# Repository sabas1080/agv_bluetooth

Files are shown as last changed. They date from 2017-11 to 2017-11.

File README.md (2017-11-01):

## AGV Bluetooth

AGV

Proyecto de AGV con Bluetooth y AppInventor

Proyecto publicado originalmente en mi antiguo blog [TecnologicoBJ12](http://tecnologicobj12.blogspot.mx/2011/12/control-de-un-carro-por-bluetooth.html)

Andrés Sabas @ 2011

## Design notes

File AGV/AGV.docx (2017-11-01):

INSTITUTO TECNOLOGICO DE AGUASCALIENTES

# PROYECTO AGV

INGENIERIA MECANICA

JOSUE ISAI LUEVANO MASIAS

GUSTAVO MUÑOZ LOPEZ

IVAN ALEJANDRO ORTEGA MONTAÑEZ

COLABORACION ESPECIAL:

ANDRES EDUARDO SABAS JIMENEZ

12/12/2011

AGUASCALIENTES, AGS

# Introducción

Los AGV son vehículos equipados con sistemas de guiado automática, ópticos o electromagnéticos. Pueden seguir rutas predeterminadas y tener capacidad de programación, selección de paradas, bloqueos, y otras características que requiere el control del sistema. Son vehículos equipados con sistemas de guiado automático, ópticos o electromagnéticos. Pueden seguir rutas predeterminadas y tener capacidad de programación, selección de paradas, bloqueos y otras características que requiere el control del sistema.

- Tipos:
  - Vehículos de remolque.
  - Unidades de carga.
  - Remolque de palets.
  - Tipo carretilla elevadora.
  - Vehículos de baja capacidad de carga.
- Funciones:
  - Guiado.
  - Elección de ruta.
  - Control de tráfico:
    - Control por zonas.
    - Detección de otros AG.
    - Control combinado.
  - Transferencia de la carga:
    - Manual.
    - Carga y descarga automática.
    - Rodillos y cadenas.
    - Elevadores.
    - Empujadores.
  - Gestión del sistema:
    - Técnicas de asignación de vehículos:
      - A bordo. Fuera del AGV.
      - Terminal remoto.
      - Computador central.
      - Combinación de las anteriores.
    - Monitorización.
- Aplicaciones:
  - Cuando los materiales llegan tarde a los centros de trabajo más del 5% del tiempo con un sistema manual.
  - Cuando hay más de carga y descarga en el sistema.
  - Cuando los movimientos de materiales están entre 35 y 200 cargas por hora.
  - Cuando se necesitan tres o cuatro carretillas en mínimo de dos turnos.
  - Cuando se están usando pies de rodillos o cintas transportadoras.
  - Cuando el software de control de la producción requiere conocer en tiempo real la situación de los materiales.
  - Cuando el nivel de inventario debido a piezas en proceso hace difícil subir la productividad.
  - Cuando la automatización de los centros de trabajo requiere una mayor automatización de los sistemas de transporte.
  - Cuando existe gran cantidad de productos dañados con los sistemas de transporte convencional.

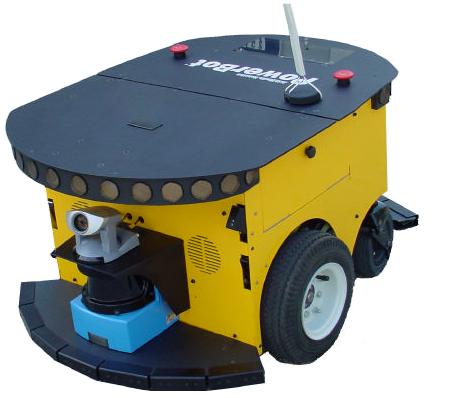
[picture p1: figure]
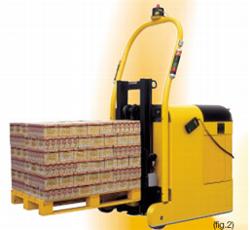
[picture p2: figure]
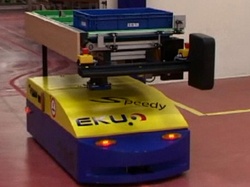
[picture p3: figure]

## Justificación.

Este proyecto estudiará algunas formas de manufactura y analizará cual es mejor en cada ocasión.

Se diseño desde cero el proyecto del AGV para que pueda realizar los parámetros dichos en el curso los cuales eran de una carga de 250 gr. Teniendo resultados satisfactorios como se pude demostrar ya con el AGV construido.

### Plan de trabajo

Este proyecto se planifica para realizarlo a lo largo del semestre. Inicialmente se procede a la documentación sobre el simulador solid Works. Antes de empezar a modelar se resolverán las tareas de control de motores y algoritmo de reconocimiento de entorno sin las cuales el simulador no funcionaría correctamente. Entonces se procede al estudio de la primera técnica, donde además de modelar el entorno e implementarlo en el programa, también se diseñará un algoritmo de planificación de trayectorias óptimo para esta técnica. También se verán las posibles mejoras en este modelo si se realiza una corrección. Una vez concluido, se procederá a realizar un ejemplar físico a escala real. Finalmente se redactará el proyecto con lo que se da por concluido.

## Objetivo General

El construir un robot AGV el cual cuenta con un diseño y funcionalidad excelentes, tiene un control remoto mediante la tecnología de bluetooth y puede cargar hasta 250gr. Poniendo en práctica los conocimientos de manufactura y electrónica se colaboro la parte electrónica con colegas en esa rama para la elaboración de este proyecto.

## Objetivos

  - Control de motores: Una vez determinadas las acciones a realizar por parte del AGV, es necesario calcular los mandos que controlan los motores. Con el fin de poder regular la velocidad de los mismos hay que diseñar un control; por ejemplo un PID o proporcional.
  - Algoritmo de reconocimiento del entorno: Planificación de los movimientos del AGV con el objeto de que se aprenda el entorno cuando es desconocido.
  - Algoritmo de planificación de trayectorias: Para la demostración de la eficiencia de las técnicas de modelado es necesario mover al AGV por el entorno para poder medir las principales características que debe tener un buen modelo: tiempo de computación, eficacia de la planificación, facilidad de actualización del modelo con nuevas medidas de los sensores y capacidad de adaptación a los cambios.

## Descripción

A la hora de resolver el problema se tiene que tener en cuenta que hay dos tipos de problemas:

Corto plazo: Evitar la colisión contra obstáculos en tiempo real por lo que no se puede usar algoritmos complicados con cálculos complejos ni tener un modelo que guarde un volumen de información tal, que procesarlo en tiempo real sea inviable.

Largo plazo: El modelo tiene que tener una cantidad de información lo suficientemente precisa para que el AGV se pueda mover por el entorno.

Se buscara un compromiso entre estas dos características, deduciendo cual es más indicada en cada caso...

### Recursos

Para la realización del proyecto se dispone de un simulador. Este simulador sitúa al AGV en un entorno creado por el usuario, calculará las medidas de los sensores en función de los obstáculos y moverá al AGV según lo que le indique una función denominada ‘Calcula mando’. Esta función recibe como información del simulador la medida de los sensores y envía al simulador el mando que se tiene que aplicar a los actuadores del AGV.

A grandes rasgos se muestra la construcción elaborada de este robot AGV con los parámetros establecidos en el curso, fotografías y fichas técnicas que contiene este proyecto.

### PARTES PRINCIPALES AGV

Estructura principal (chasís) del AGV

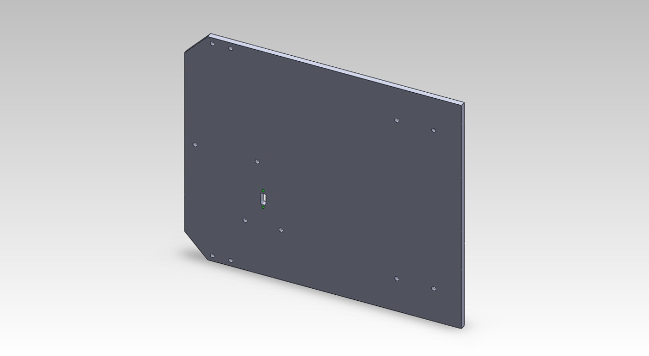
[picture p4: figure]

Brida superior para motor en el tren motriz.

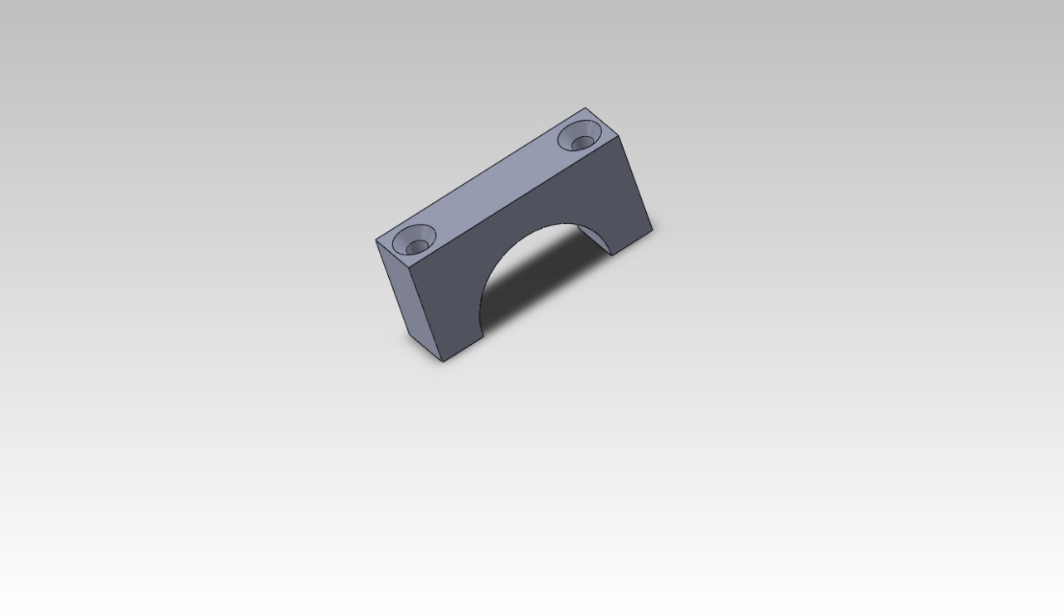
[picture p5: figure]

Brida inferior para motor en el tren motriz.

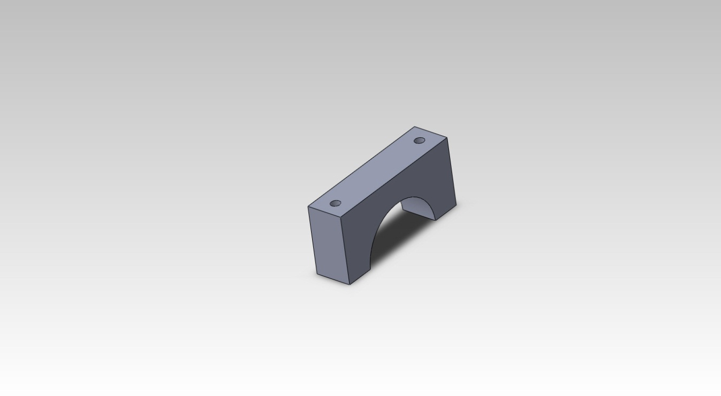
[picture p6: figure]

Motores para tren motriz.

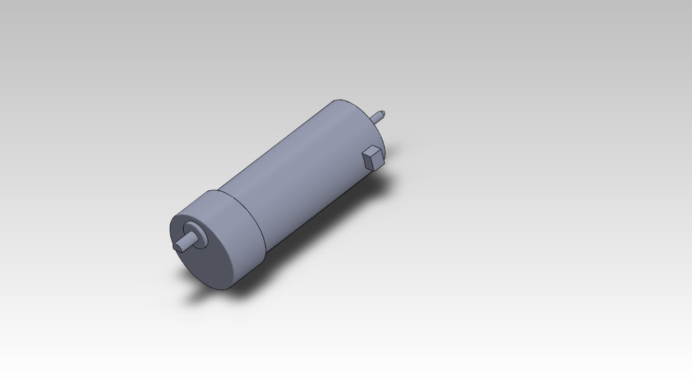
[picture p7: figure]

Brida superior para motor de sistema de enganche.

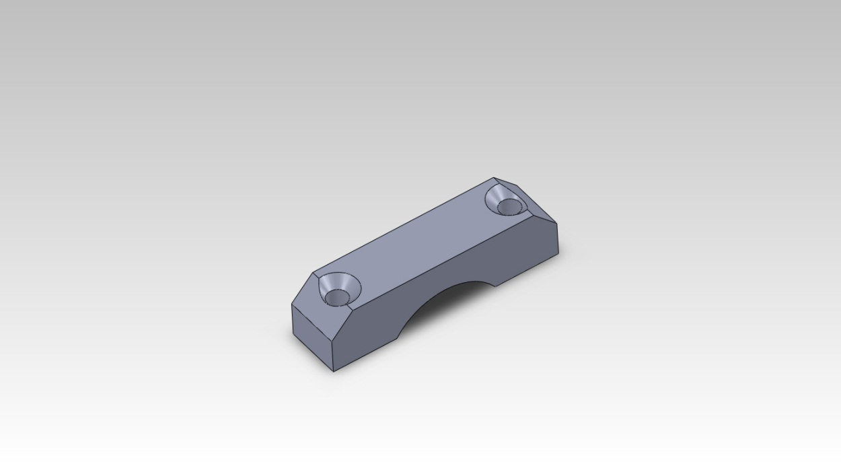
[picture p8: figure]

Unión para bridas superior e inferior del motor.

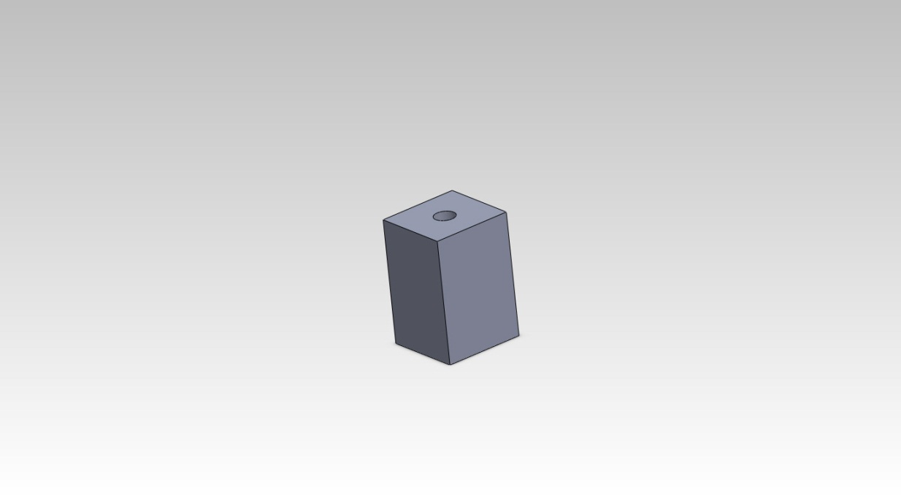
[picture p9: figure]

Brida inferior para motor de sistema de enganche.

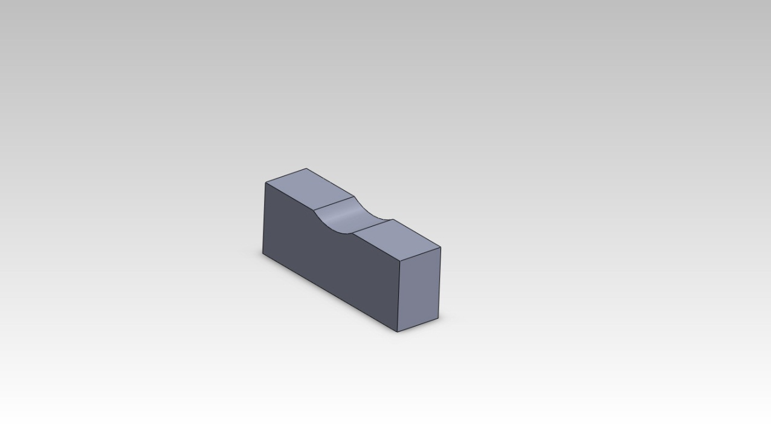
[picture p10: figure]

Motor del sistema de enganche.

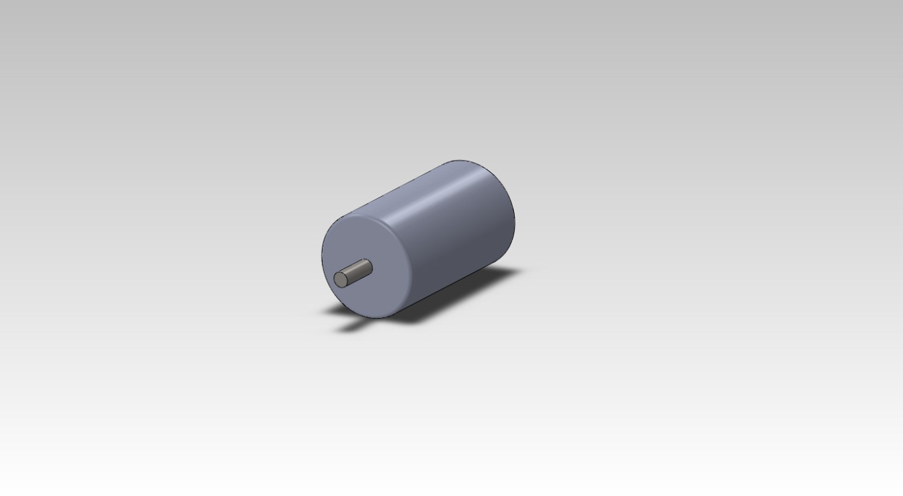
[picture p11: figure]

Rueda del encoder.

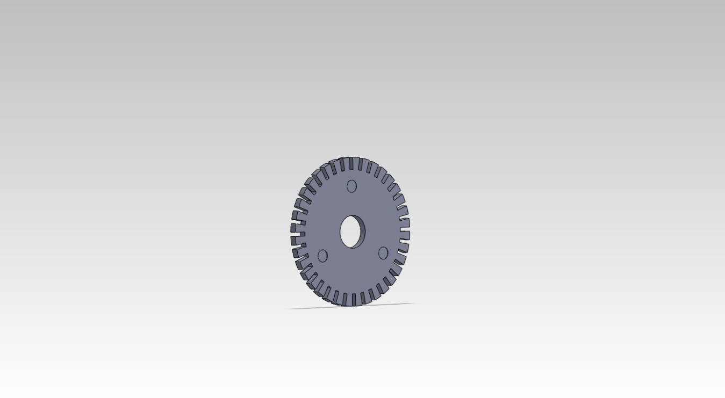
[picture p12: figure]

Soporte del sistema del encoder.

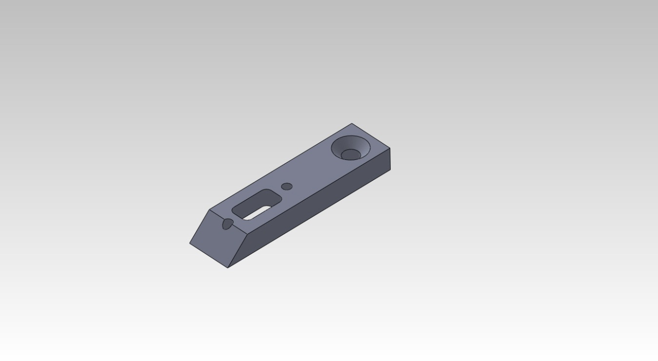
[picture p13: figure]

Sensor para la rueda del encoder.

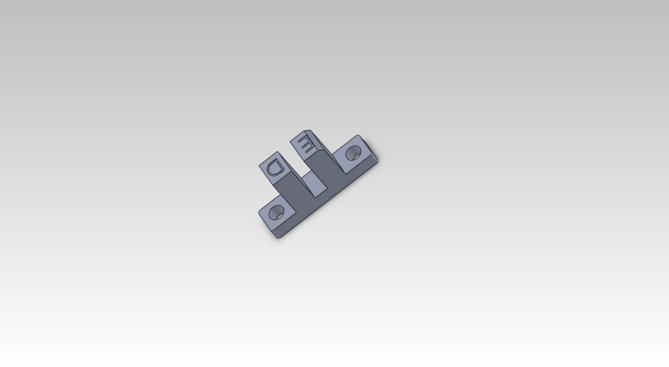
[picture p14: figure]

Engrane(gusano) para el motor del sistema de enganche.

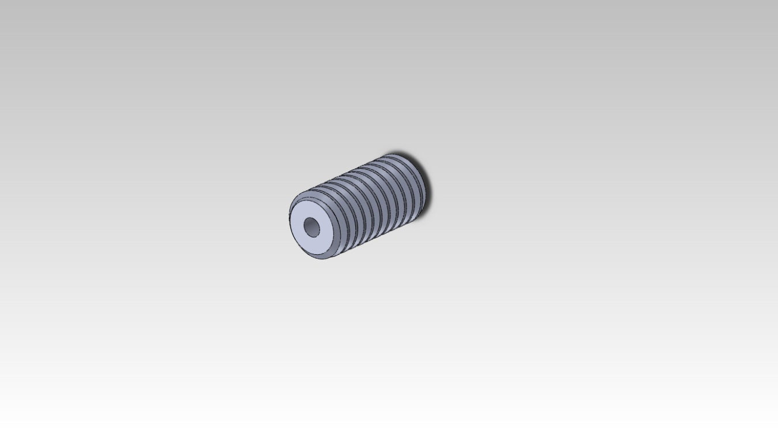
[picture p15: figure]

Placa principal para el sistema de enganche.

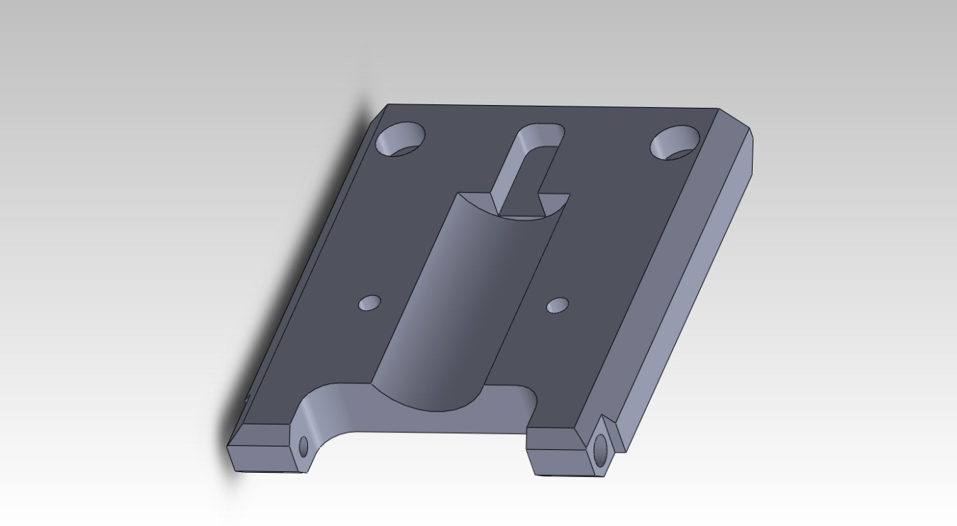
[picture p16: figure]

Soporte para placa principal del sistema de enganche.

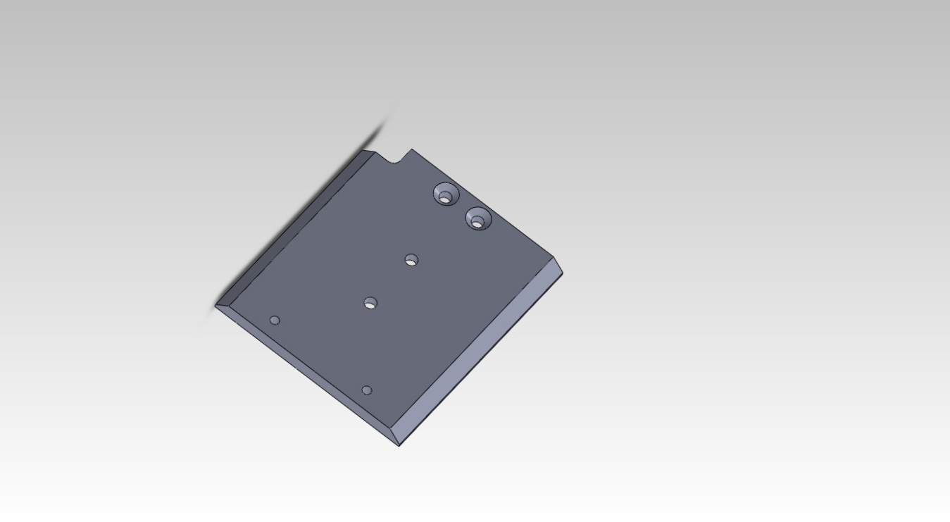
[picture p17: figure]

Unión placa principal con el soporte.

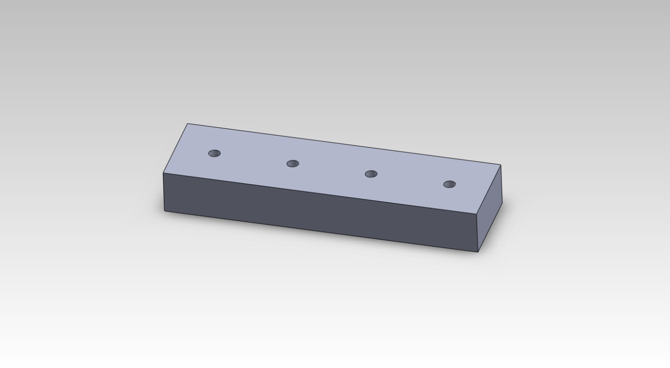
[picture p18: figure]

Engrane principal para sistema de enganche, Apertura y agarre.

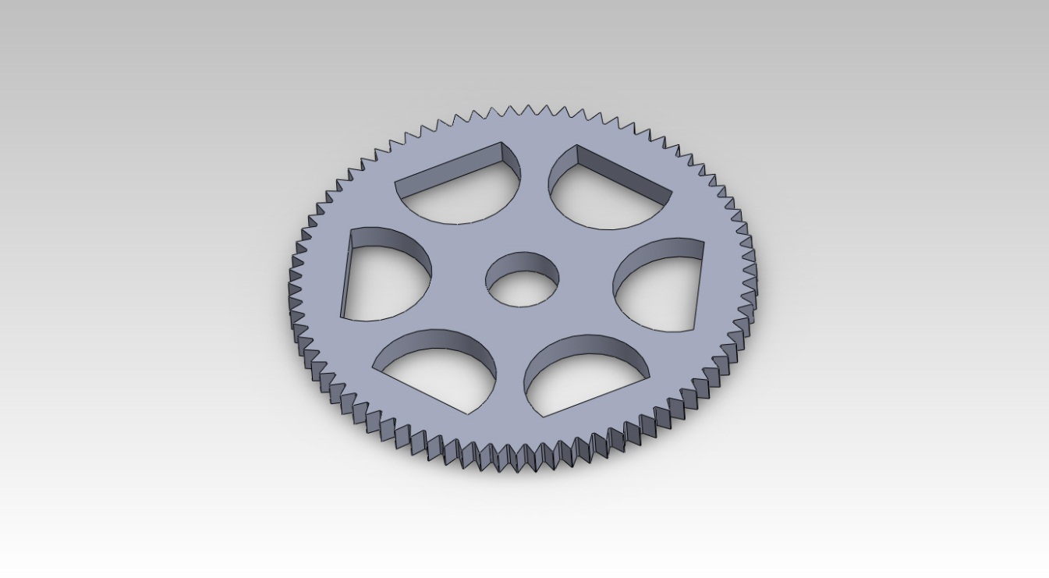
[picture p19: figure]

Brazo del sistema de enganche “pinzas”.

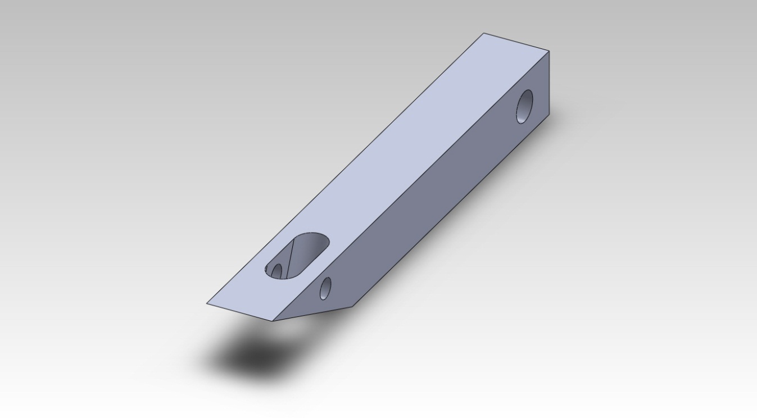
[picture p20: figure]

NOTA: Algunos de los componentes en gran parte los motrices se repiten asi como los engranes.

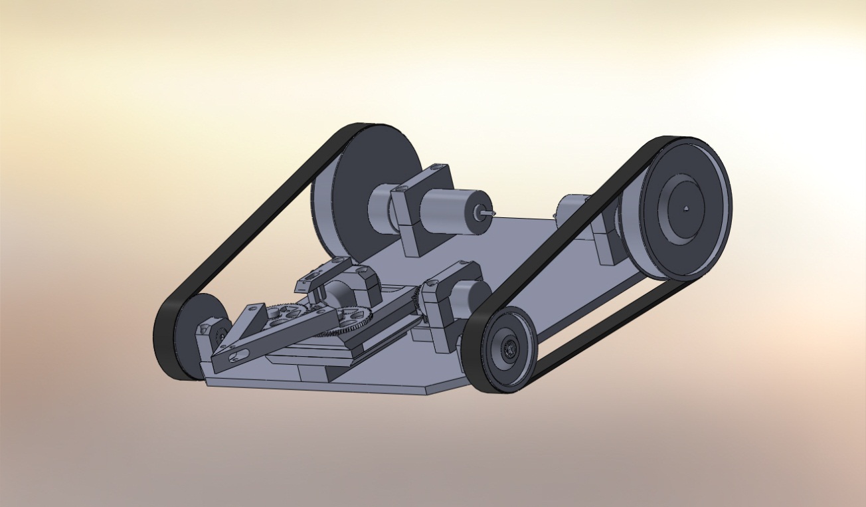
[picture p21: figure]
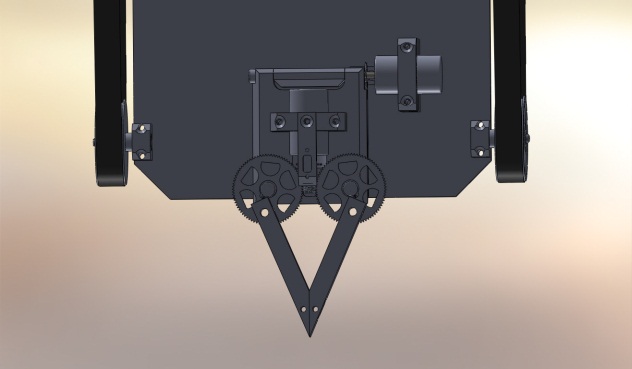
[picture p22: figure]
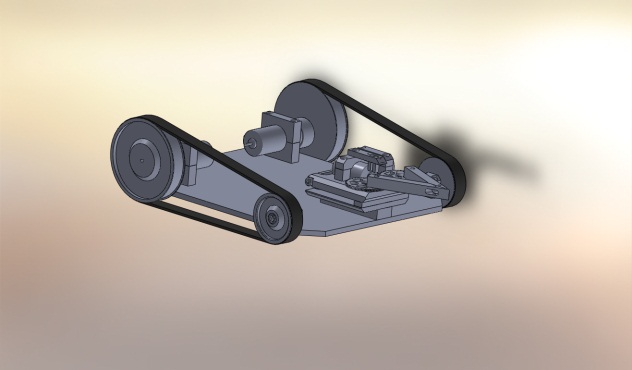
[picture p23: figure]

### Conclusión

Los vehículos auto guiados (AGV) han atraído siempre interés en el desarrollo tecnológico.

El funcionamiento óptimo de un AGV se basa en que éste sea capaz de planificar sus propias trayectorias. Para conseguir este objetivo es crucial disponer de datos suficientemente precisos acerca de la existencia y localización de los obstáculos. Esto es lo que se denomina entorno.

Los AGV son herramientas para industria muy importantes hoy en día ya que dan mayor rendimiento así como mayor productividad en la industria tienen diversas aplicaciones desde la de diversión hasta militares por sus capacidades de evadir obstáculos y reconocer el terreno en el cual son conducidos.

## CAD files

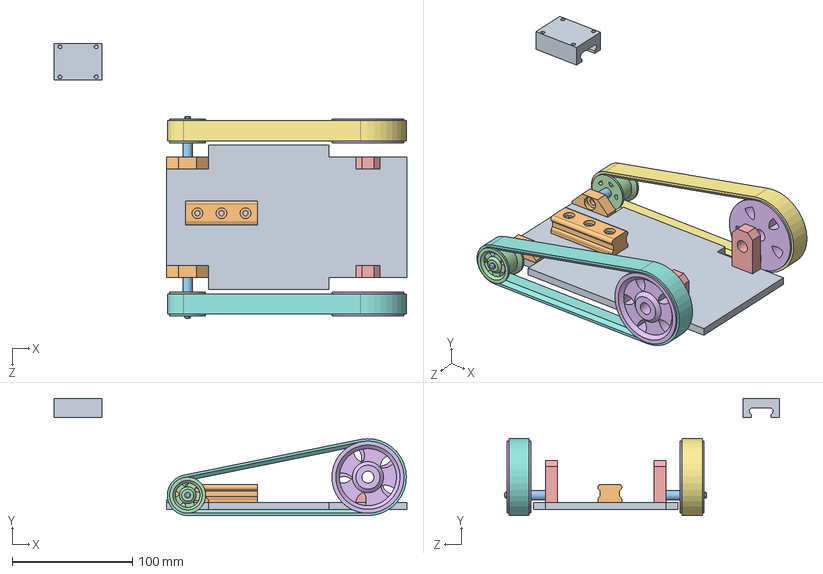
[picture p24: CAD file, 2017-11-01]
AGV/Modelo SolidWork/AGV.SLDASM
293.7 x 97.5 x 228.4 mm
Correa1-17^AGV
Correa2-19^AGV

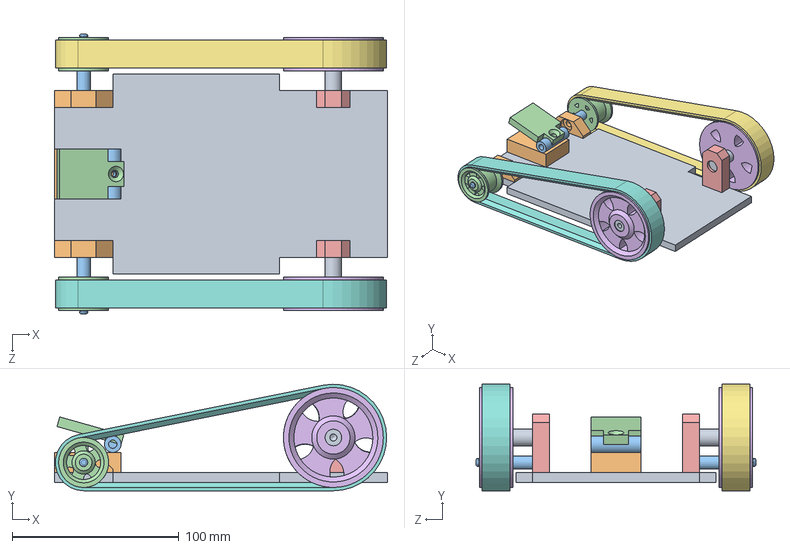
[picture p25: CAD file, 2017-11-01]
AGV/Modelo SolidWork/AGV avance.SLDASM
200.0 x 64.0 x 168.0 mm
Correa1-4^AGV
Correa2-5^AGV

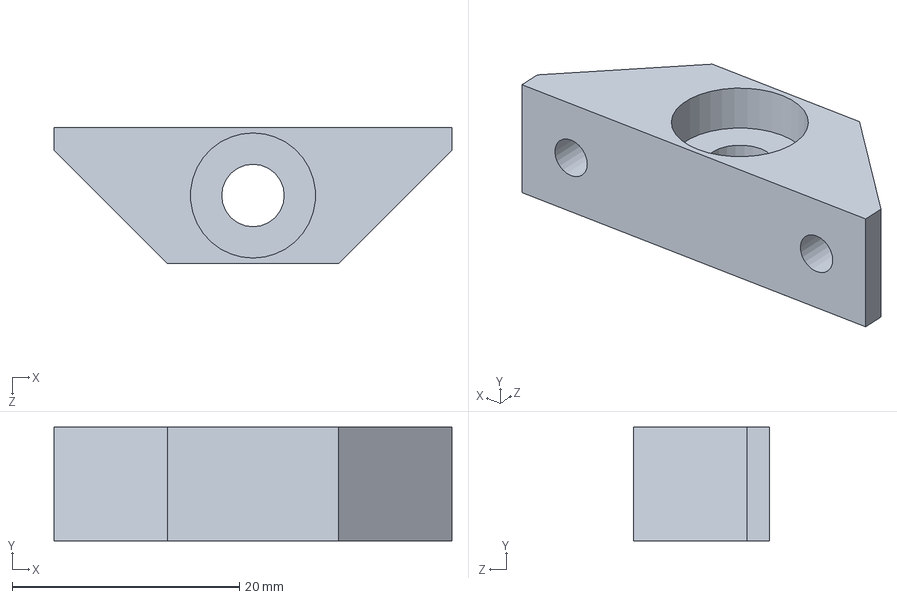
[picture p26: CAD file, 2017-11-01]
AGV/Modelo SolidWork/0008.sldprt
35.0 x 10.0 x 12.0 mm

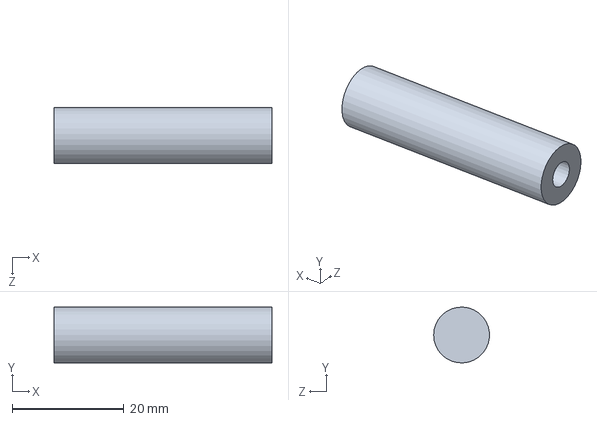
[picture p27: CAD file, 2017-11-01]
AGV/Modelo SolidWork/0011.sldprt
39.0 x 9.99 x 9.97 mm

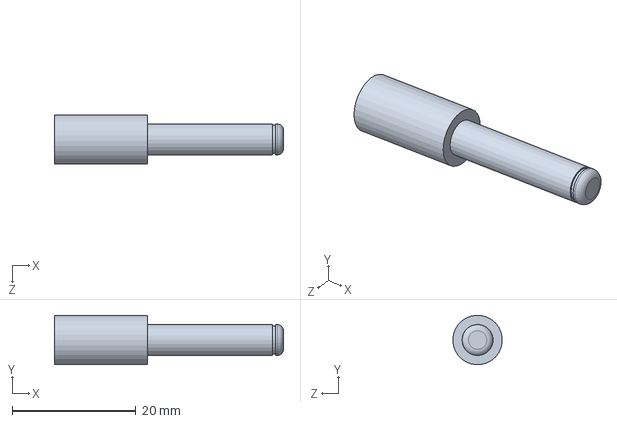
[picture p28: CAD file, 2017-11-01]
AGV/Modelo SolidWork/0010.sldprt
37.0 x 7.99 x 7.98 mm

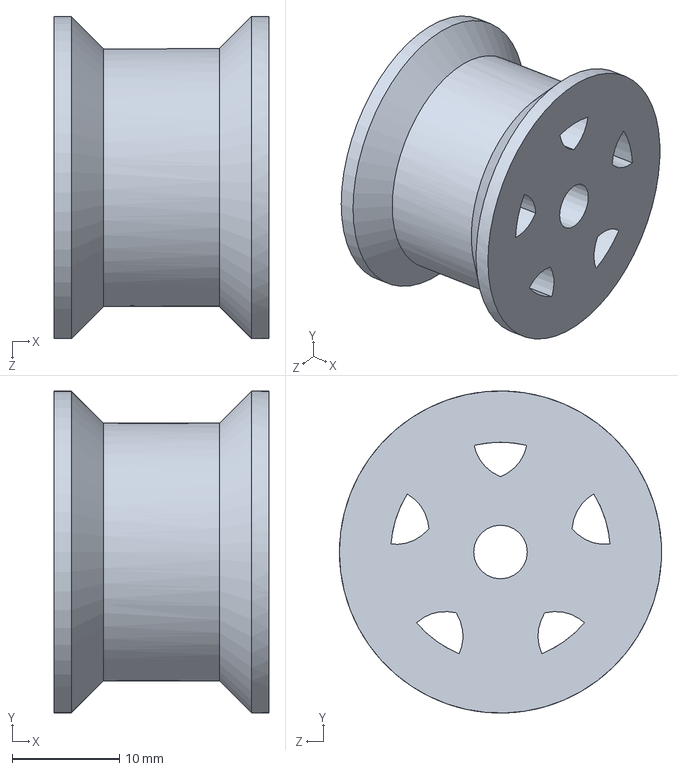
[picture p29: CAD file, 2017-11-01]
AGV/Modelo SolidWork/0005.sldprt
20.0 x 30.0 x 30.0 mm

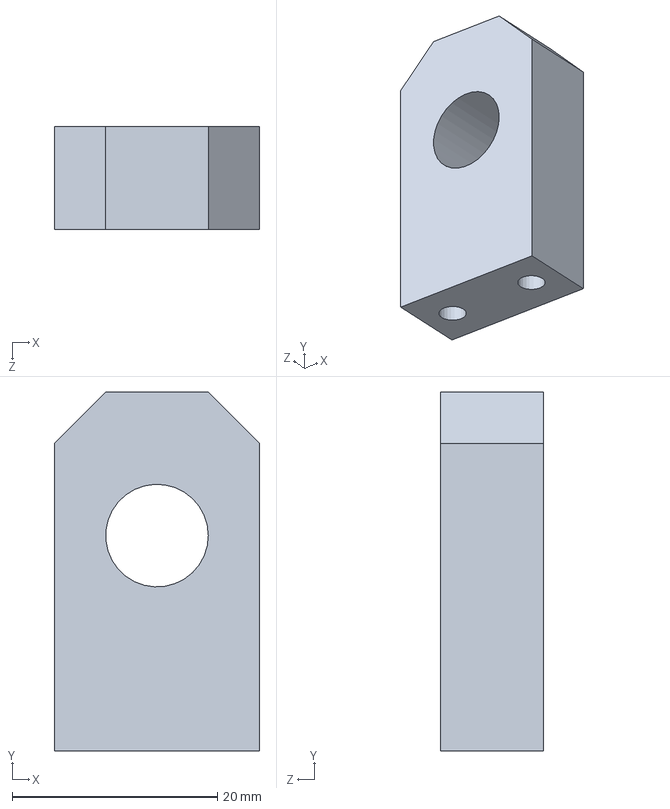
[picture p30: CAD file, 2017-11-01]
AGV/Modelo SolidWork/0009.sldprt
20.0 x 35.0 x 10.0 mm

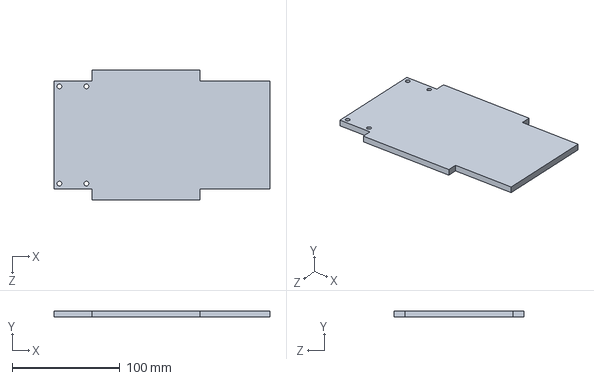
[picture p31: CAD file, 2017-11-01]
AGV/Modelo SolidWork/0004.sldprt
200.0 x 6.00 x 120.0 mm

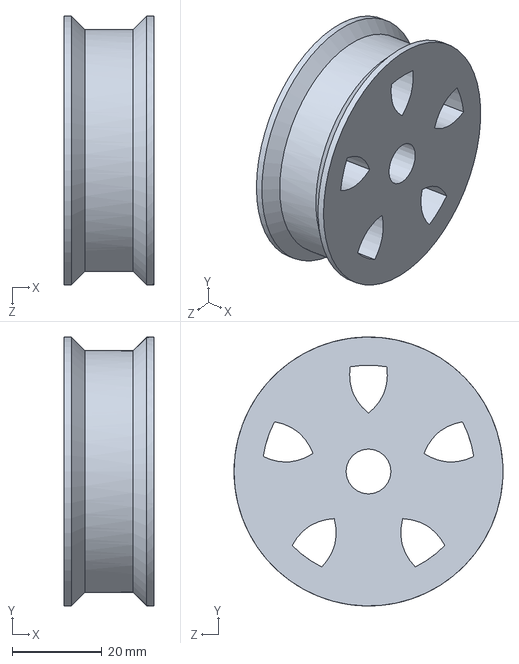
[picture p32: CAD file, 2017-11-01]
AGV/Modelo SolidWork/0001.sldprt
20.0 x 60.0 x 60.0 mm

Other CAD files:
AGV/Modelo SolidWork/0024.sldprt
AGV/Modelo SolidWork/Correa1-4^AGV.sldprt
AGV/Modelo SolidWork/0021.sldprt
AGV/Modelo SolidWork/0023.sldprt
AGV/Modelo SolidWork/0025.sldprt
AGV/Modelo SolidWork/0022.sldprt
AGV/Modelo SolidWork/Correa2-5^AGV.sldprt

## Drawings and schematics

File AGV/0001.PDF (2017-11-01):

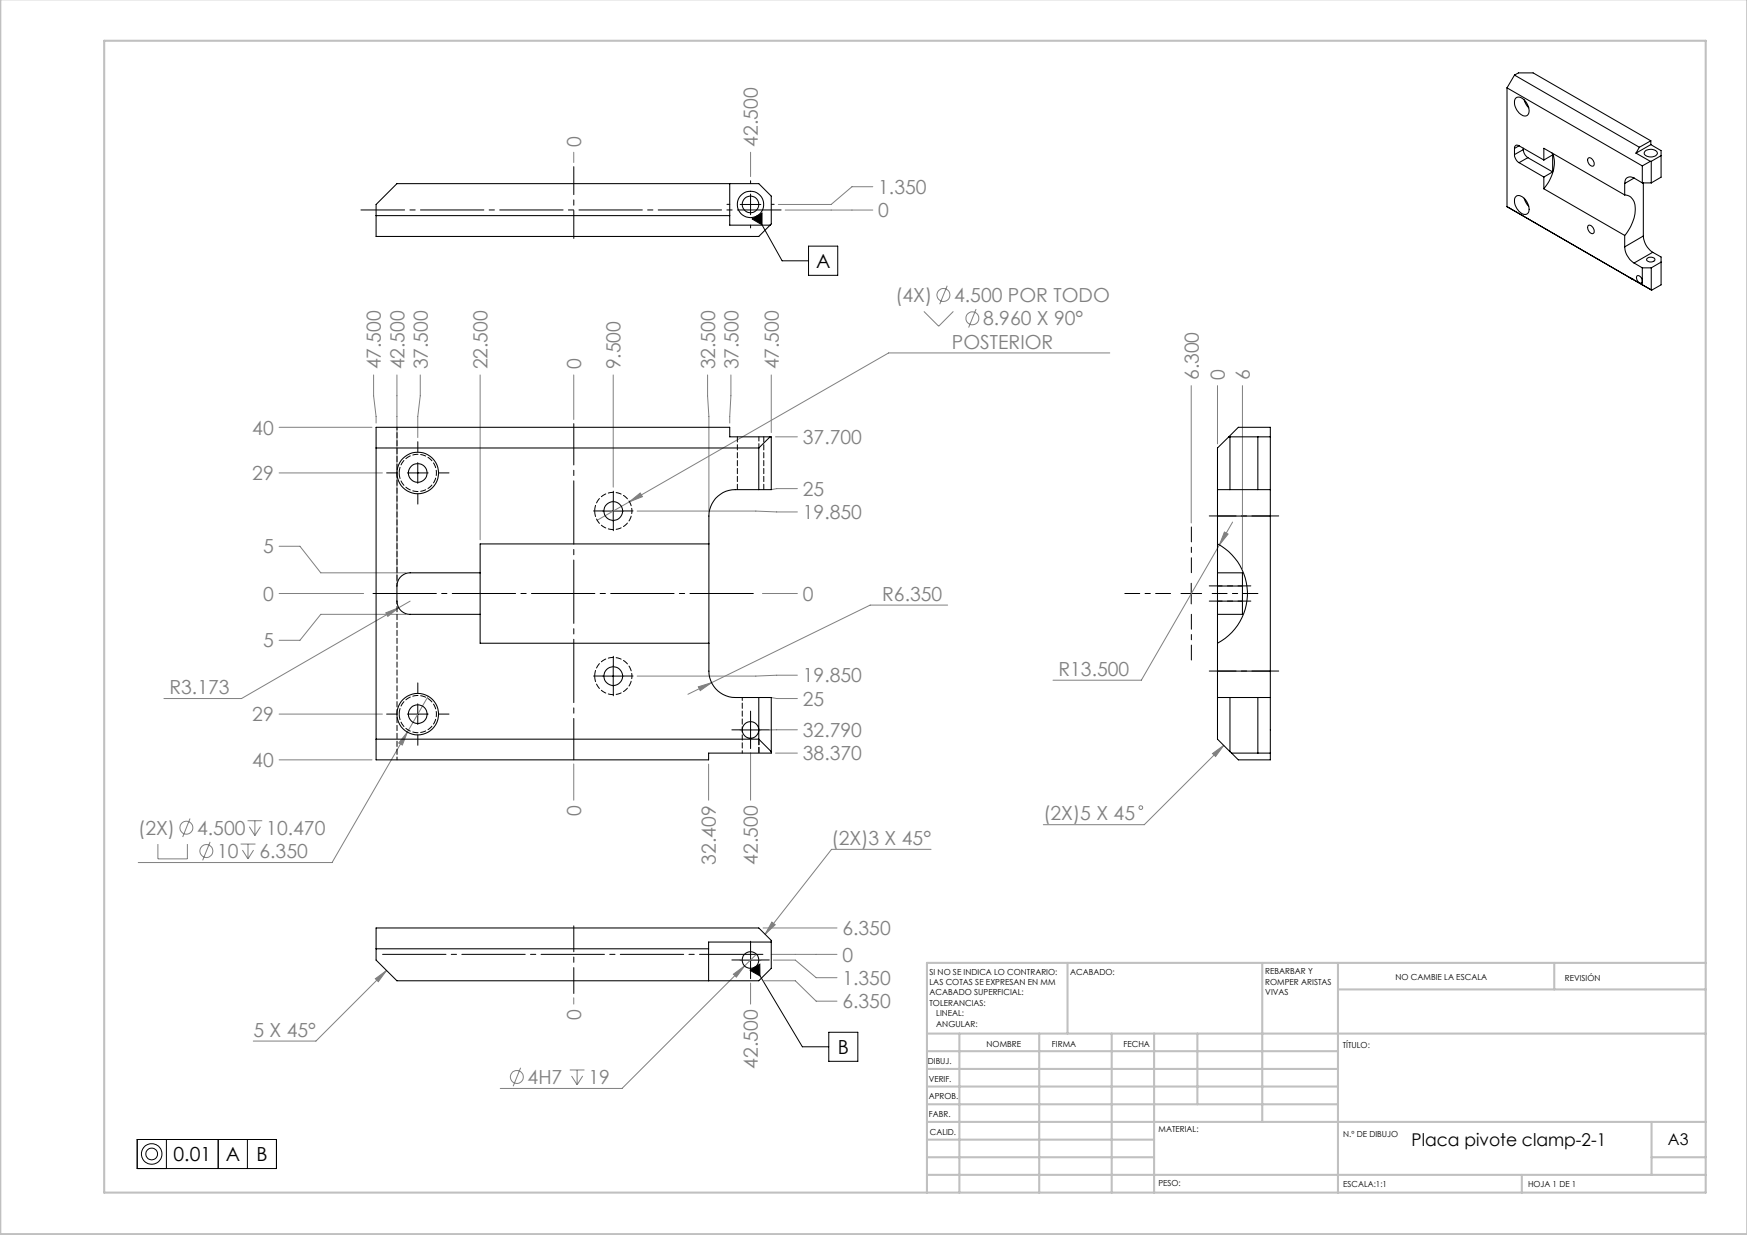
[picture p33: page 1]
(4X) 4.500 POR TODO 8.960 X 90°; Placa pivote clamp-2-1; ESCALA:1:1; HOJA 1 DE 1; NO CAMBIE LA ESCALA; REVISIÓN; REBARBAR Y ROMPER ARISTAS; SI NO SE INDICA LO CONTRARIO:; ACABADO:

LAS COTAS SE EXPRESAN EN MM
ACABADO SUPERFICIAL:
TOLERANCIAS:
LINEAL:
ANGULAR:

NOMBRE | FIRMA | FECHA | | | | TÍTULO:

DIBUJ.
VERIF.
APROB.
FABR.
CALID. | | | | MATERIAL: | N.º DE DIBUJO | A3

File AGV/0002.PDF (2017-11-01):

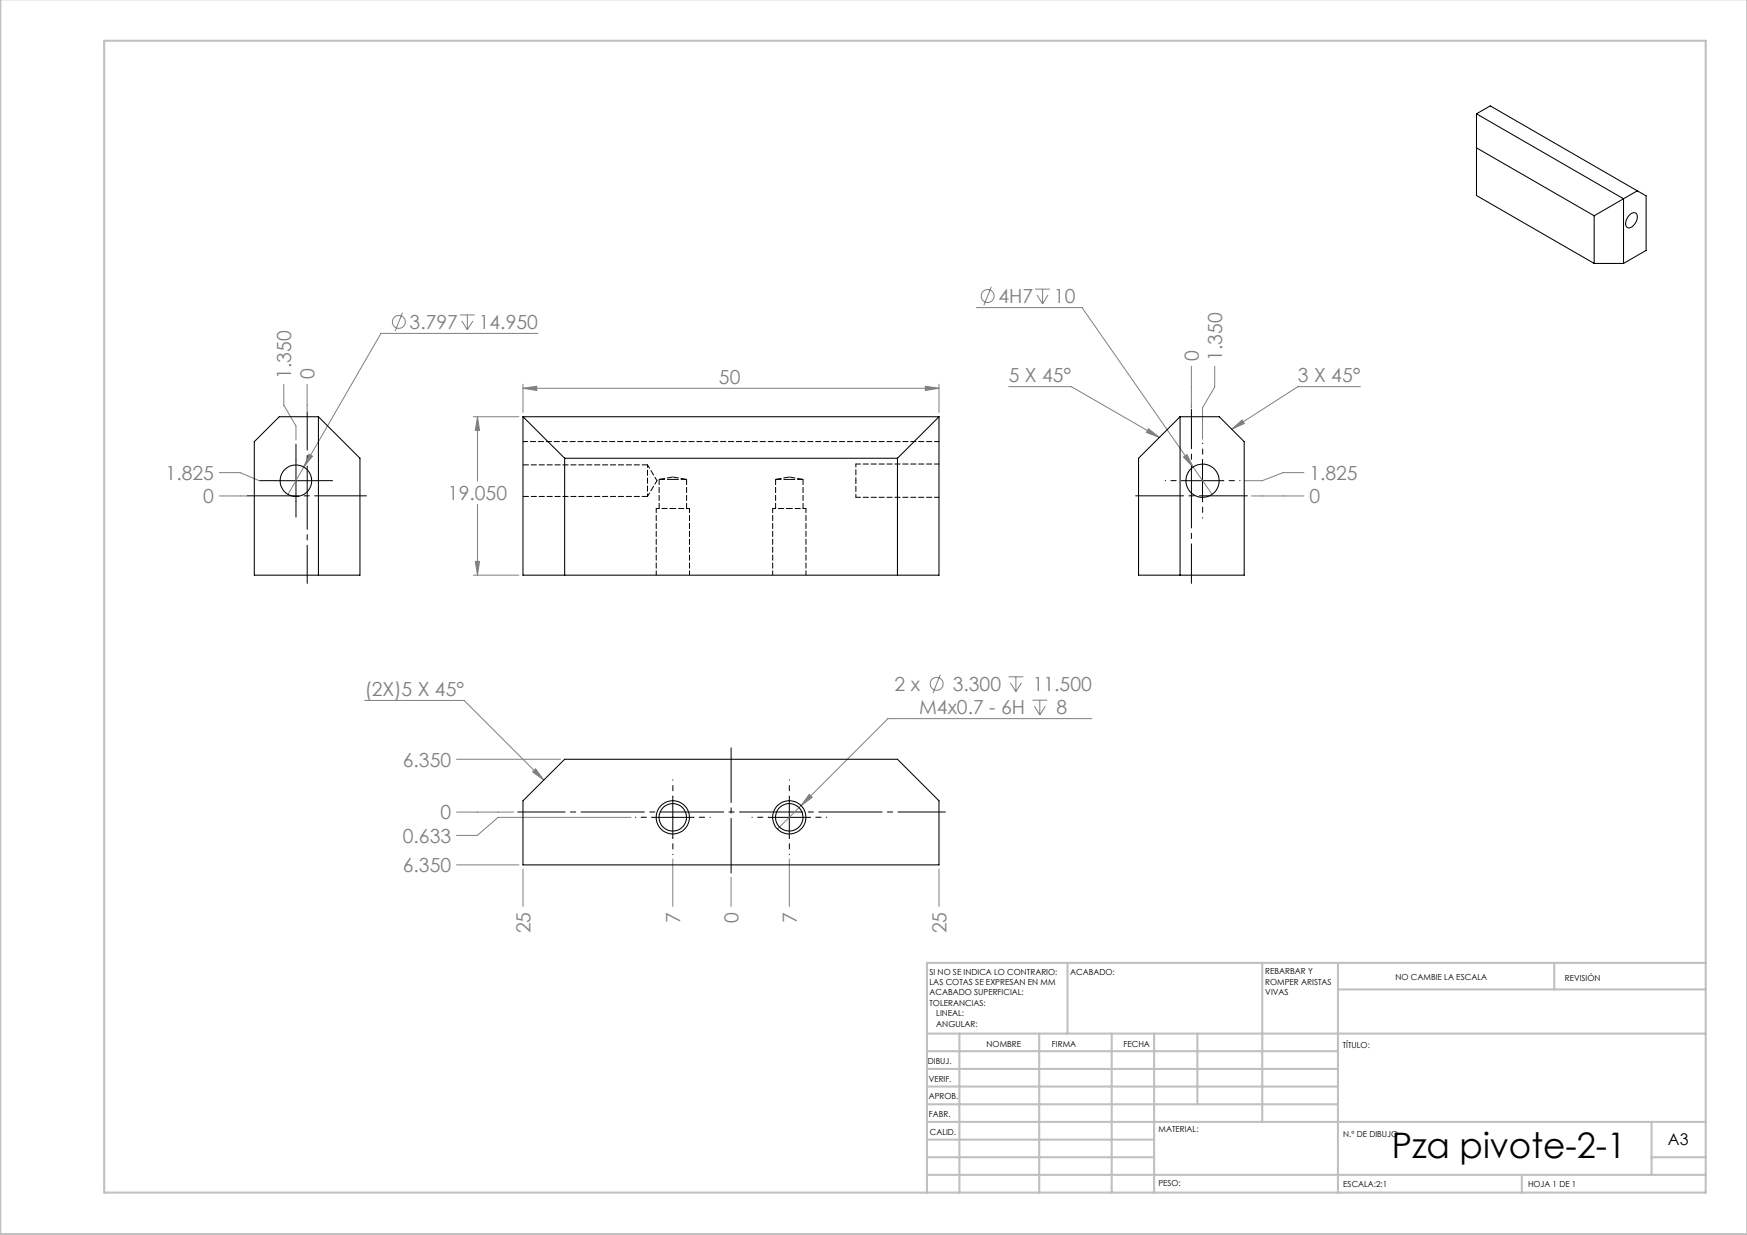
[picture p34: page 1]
ESCALA:2:1; HOJA 1 DE 1; NO CAMBIE LA ESCALA; REVISIÓN; REBARBAR Y ROMPER ARISTAS; SI NO SE INDICA LO CONTRARIO:; ACABADO:

LAS COTAS SE EXPRESAN EN MM
ACABADO SUPERFICIAL:
TOLERANCIAS:
LINEAL:
ANGULAR:

NOMBRE | FIRMA | FECHA | | | | TÍTULO:
CALID. | | | | MATERIAL: | Pza pivote-2-1 PESO: N.º DE DIBUJO | A3

DIBUJ.
VERIF.
APROB.
FABR.

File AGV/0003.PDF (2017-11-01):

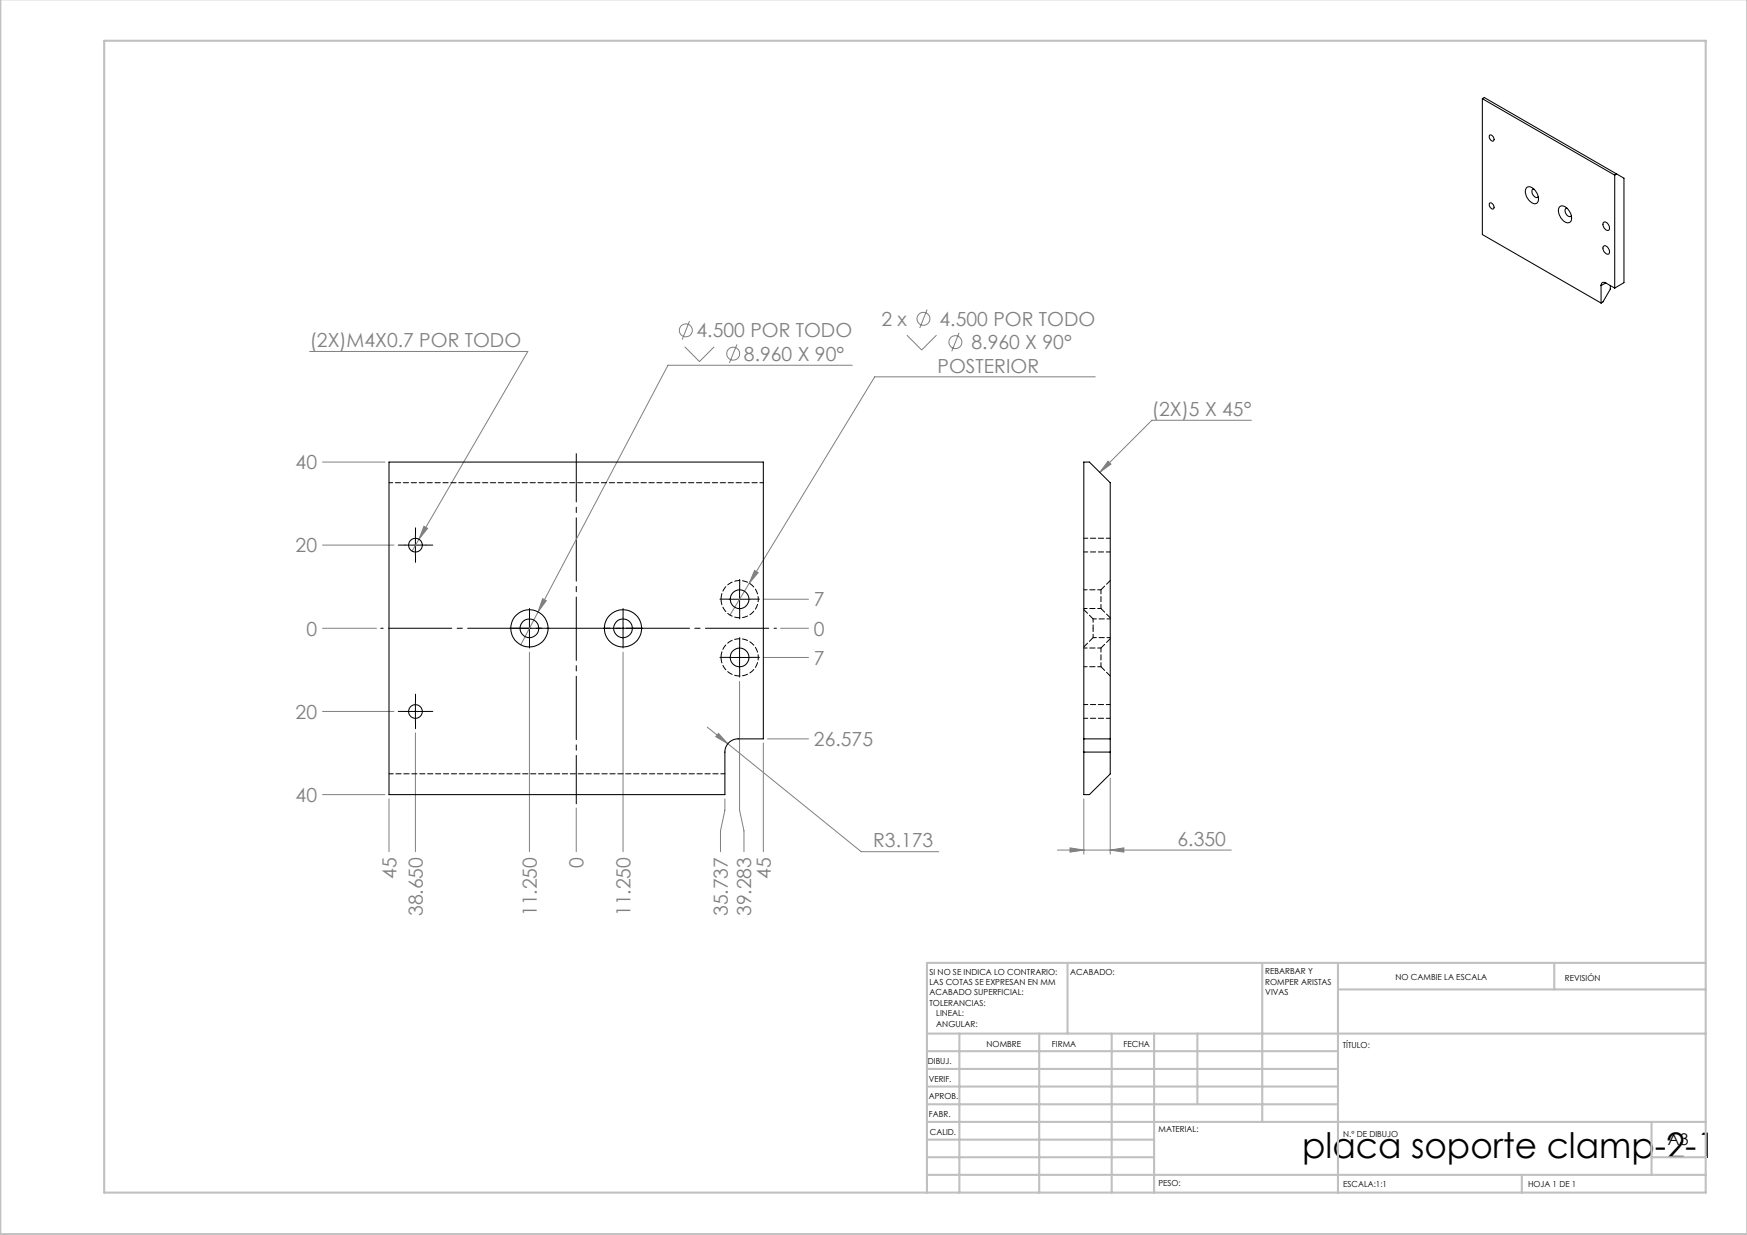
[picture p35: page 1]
4.500 POR TODO 8.960 X 90°; 4.500 POR TODO; (2X)M4X0.7 POR TODO; ESCALA:1:1; HOJA 1 DE 1; NO CAMBIE LA ESCALA; REVISIÓN; REBARBAR Y ROMPER ARISTAS; SI NO SE INDICA LO CONTRARIO:; ACABADO:

LAS COTAS SE EXPRESAN EN MM
ACABADO SUPERFICIAL:
TOLERANCIAS:
LINEAL:
ANGULAR:

NOMBRE | FIRMA | FECHA | | | | TÍTULO:
CALID. | | | | MATERIAL: placa soporte clamp-2-1 PESO: | N.º DE DIBUJO | A3

DIBUJ.
VERIF.
APROB.
FABR.

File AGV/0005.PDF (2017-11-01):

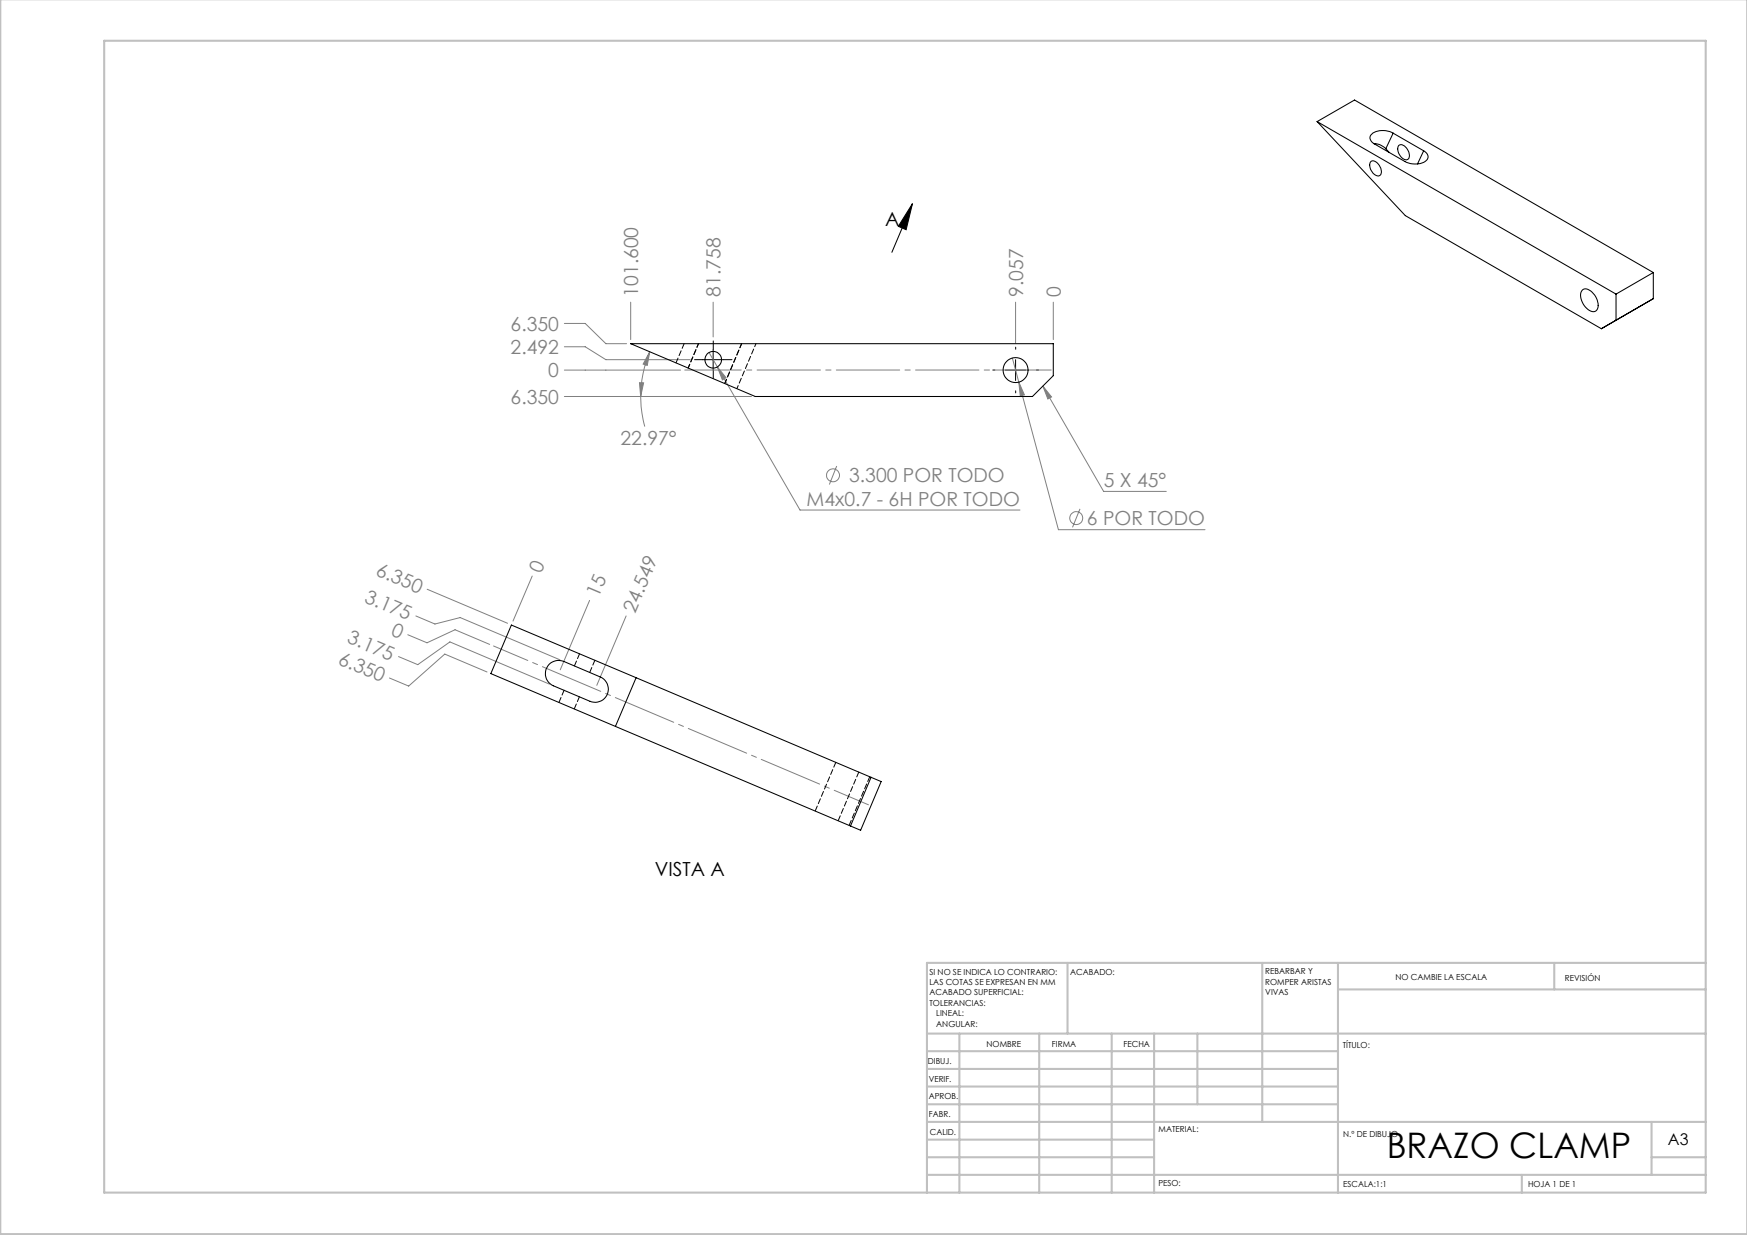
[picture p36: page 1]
6 POR TODO; 5 X 45° 3.300 POR TODO M4x0.7 - 6H POR TODO; VISTA A; ESCALA:1:1; HOJA 1 DE 1; NO CAMBIE LA ESCALA; REVISIÓN; REBARBAR Y ROMPER ARISTAS; SI NO SE INDICA LO CONTRARIO:; ACABADO:

LAS COTAS SE EXPRESAN EN MM
ACABADO SUPERFICIAL:
TOLERANCIAS:
LINEAL:
ANGULAR:

NOMBRE | FIRMA | FECHA | | | | TÍTULO:
CALID. | | | | MATERIAL: | BRAZO CLAMP PESO: N.º DE DIBUJO | A3

DIBUJ.
VERIF.
APROB.
FABR.

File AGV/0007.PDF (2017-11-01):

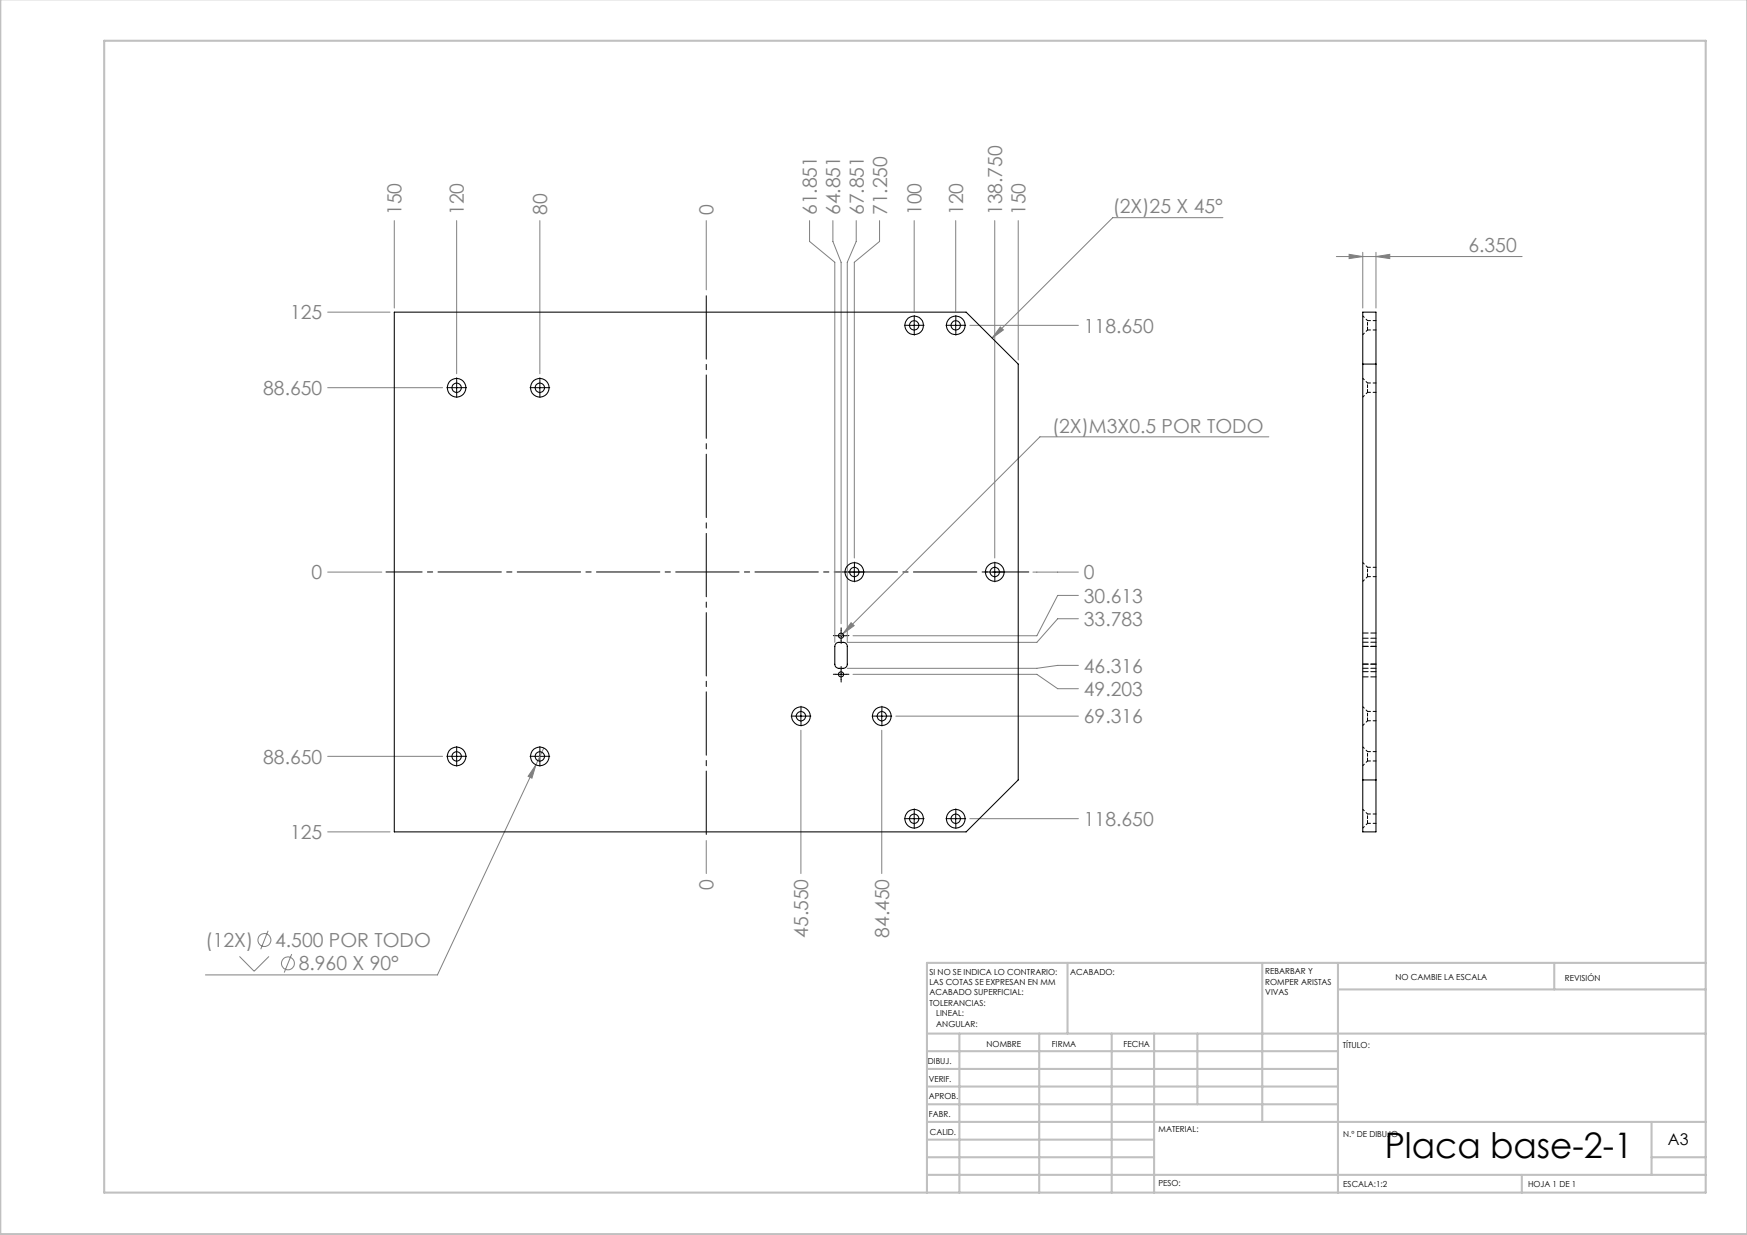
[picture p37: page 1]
(12X) 4.500 POR TODO 8.960 X 90°; (2X)M3X0.5 POR TODO; ESCALA:1:2; HOJA 1 DE 1; NO CAMBIE LA ESCALA; REVISIÓN; REBARBAR Y ROMPER ARISTAS; SI NO SE INDICA LO CONTRARIO:; ACABADO:

LAS COTAS SE EXPRESAN EN MM
ACABADO SUPERFICIAL:
TOLERANCIAS:
LINEAL:
ANGULAR:

NOMBRE | FIRMA | FECHA | | | | TÍTULO:
CALID. | | | | MATERIAL: | Placa base-2-1 PESO: N.º DE DIBUJO | A3

DIBUJ.
VERIF.
APROB.
FABR.

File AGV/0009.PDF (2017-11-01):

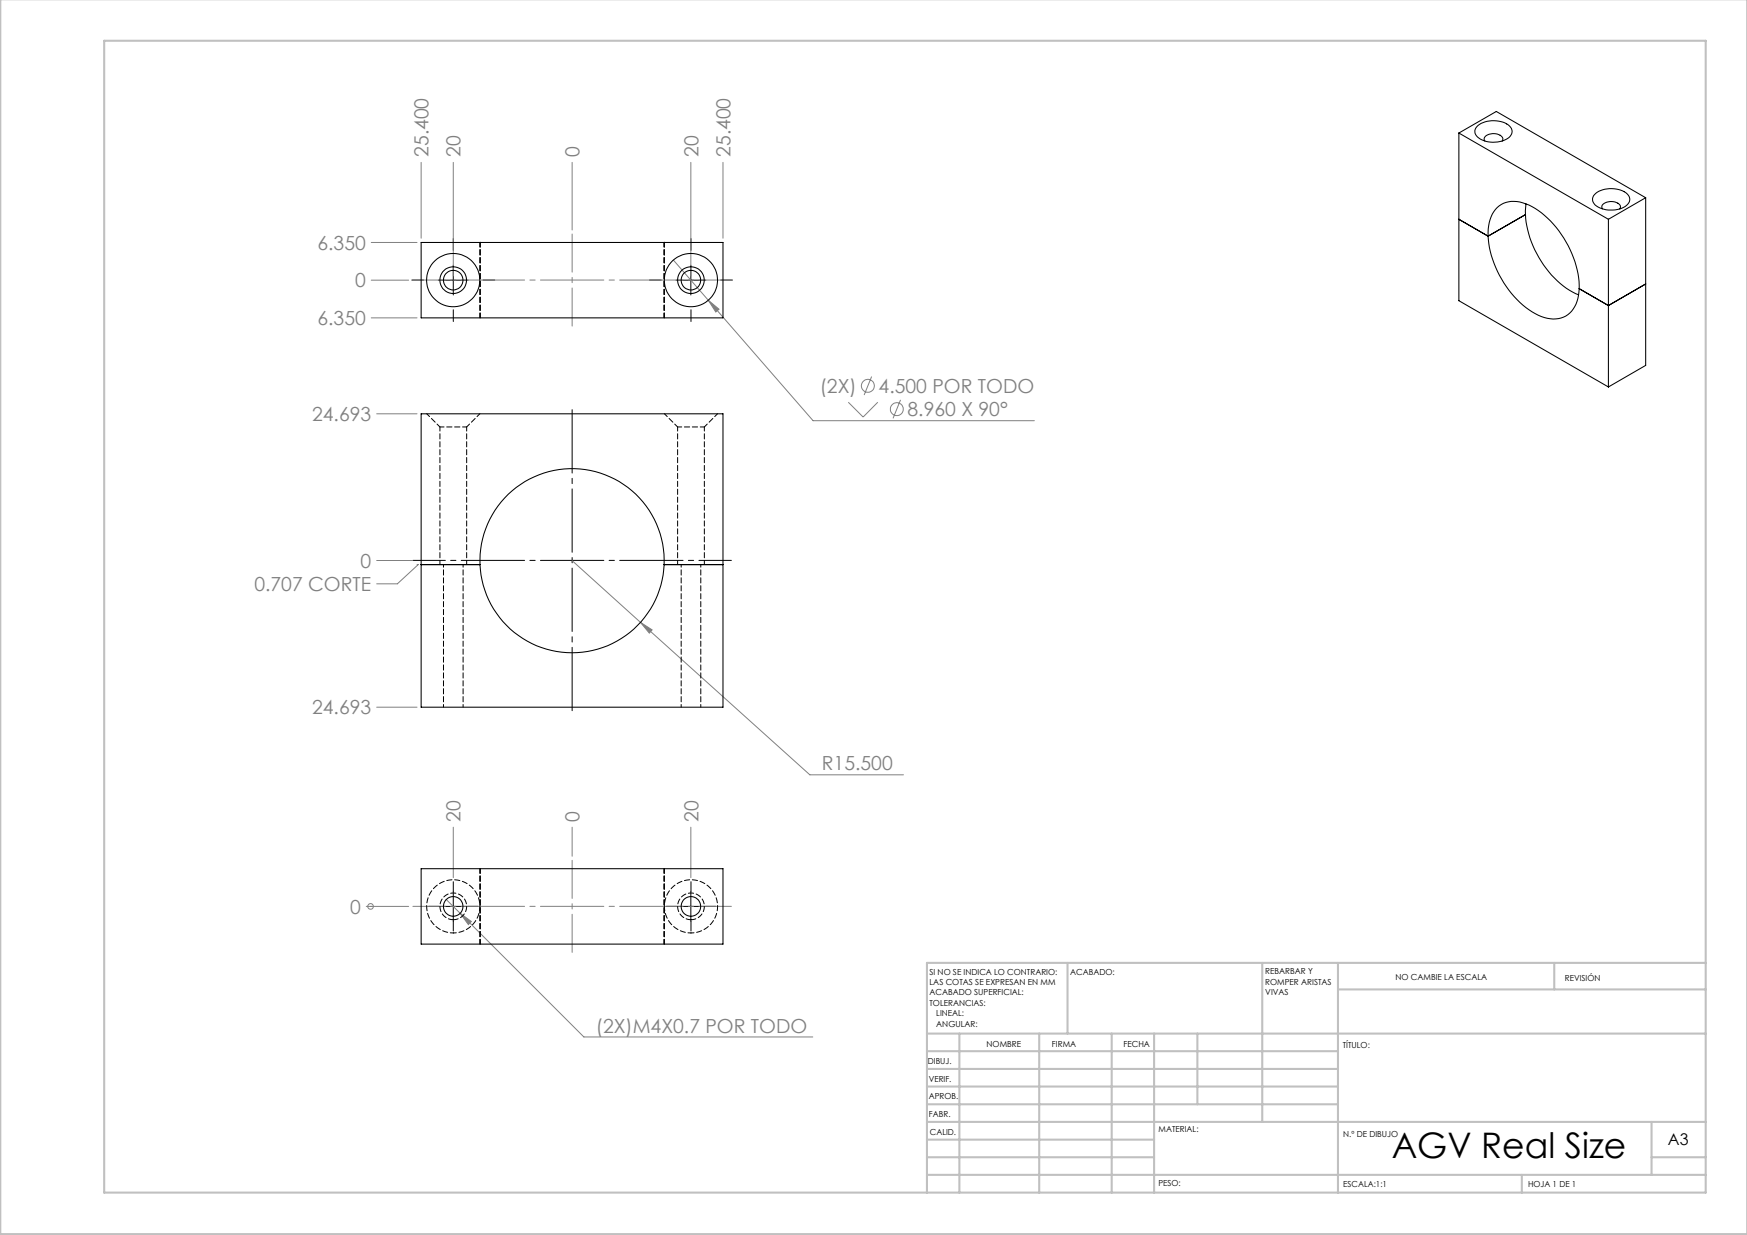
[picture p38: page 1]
0.707 CORTE; (2X)M4X0.7 POR TODO; (2X) 4.500 POR TODO 8.960 X 90°; ESCALA:1:1; HOJA 1 DE 1; NO CAMBIE LA ESCALA; REVISIÓN; REBARBAR Y ROMPER ARISTAS; SI NO SE INDICA LO CONTRARIO:; ACABADO:

LAS COTAS SE EXPRESAN EN MM
ACABADO SUPERFICIAL:
TOLERANCIAS:
LINEAL:
ANGULAR:

NOMBRE | FIRMA | FECHA | | | | TÍTULO:
CALID. | | | | MATERIAL: | AGV Real Size PESO: N.º DE DIBUJO | A3

DIBUJ.
VERIF.
APROB.
FABR.

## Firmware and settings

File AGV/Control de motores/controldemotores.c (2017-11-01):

#include <18F4550.h>

#FUSES NOWDT                    //No Watch Dog Timer
#FUSES WDT128                   //Watch Dog Timer uses 1:128 Postscale
#FUSES PLL1                     //No PLL PreScaler
#FUSES CPUDIV1                  //No System Clock Postscaler
#FUSES USBDIV                   //USB clock source comes from PLL divide by 2
#FUSES HS                       //High speed Osc (> 4mhz for PCM/PCH) (>10mhz for PCD)
#FUSES FCMEN                    //Fail-safe clock monitor enabled
#FUSES IESO                     //Internal External Switch Over mode enabled
#FUSES PUT                      //Power Up Timer
#FUSES NOBROWNOUT               //No brownout reset
#FUSES BORV20                   //Brownout reset at 2.0V
#FUSES VREGEN                   //USB voltage regulator enabled
#FUSES PBADEN                   //PORTB pins are configured as analog input channels on RESET
#FUSES LPT1OSC                  //Timer1 configured for low-power operation
#FUSES MCLR                     //Master Clear pin enabled
#FUSES STVREN                   //Stack full/underflow will cause reset
#FUSES NOLVP                    //No low voltage prgming, B3(PIC16) or B5(PIC18) used for I/O
#FUSES ICSP2                    //ICD uses PGC2/PGD2 pins
#FUSES NOXINST                  //Extended set extension and Indexed Addressing mode disabled (Legacy mode)
#FUSES NODEBUG                  //No Debug mode for ICD
#FUSES NOPROTECT                //Code not protected from reading
#FUSES NOCPB                    //No Boot Block code protection
#FUSES NOCPD                    //No EE protection
#FUSES NOWRT                    //Program memory not write protected
#FUSES NOWRTC                   //configuration not registers write protected
#FUSES NOWRTB                   //Boot block not write protected
#FUSES NOWRTD                   //Data EEPROM not write protected
#FUSES NOEBTR                   //Memory not protected from table reads
#FUSES NOEBTRB                  //Boot block not protected from table reads

#use delay(clock=20000000)
#use rs232(baud=9600,parity=N,xmit=PIN_C6,rcv=PIN_C7,bits=8)

//--------------------------Variables Globales--------------------------------
char CAR;

//-----------------Se le pide a picc que no mueva los TRIS de los puertos
#use FAST_IO(A)
#use FAST_IO(B)
#use FAST_IO(C)
#use FAST_IO(D)
#use FAST_IO(E)

//--------------------Interrupcion de llegada de datos-----------------------

#int_EXT2
void cerrado(void)
{
delay_ms(100);

}

#int_RDA
void  RDA_isr(void) 
{
CAR=getc();
}


//------------Subrutinas de acciones de los motores de avance-----------------
void adelante()
{
   output_high(PIN_B6);
   output_high(PIN_B7);
   output_high(PIN_D0);
   output_high(PIN_D2);
   output_low(PIN_D1);
   output_low(PIN_D3);  
}

void atras()
{
   output_high(PIN_B6);
   output_high(PIN_B7);
   output_high(PIN_D1);
   output_high(PIN_D3);
   output_low(PIN_D0);
   output_low(PIN_D2);
}
void derecha_adelante()
{
   output_high(PIN_B6);
   output_low(PIN_B7);
   output_high(PIN_D0);
   output_low(PIN_D2);
   output_low(PIN_D1);
   output_low(PIN_D3);
}
void izquierda_adelante()
{
   output_low(PIN_B6);
   output_high(PIN_B7);
   output_low(PIN_D0);
   output_high(PIN_D2);
   output_low(PIN_D1);
   output_low(PIN_D3);
}
void derecha_atras()
{
   output_high(PIN_B6);
   output_low(PIN_B7);
   output_high(PIN_D1);
   output_low(PIN_D3);
   output_low(PIN_D0);
   output_low(PIN_D2);
}
void izquierda_atras()
{
   output_low(PIN_B6);
   output_high(PIN_B7);
   output_low(PIN_D1);
   output_high(PIN_D3);
   output_low(PIN_D0);
   output_low(PIN_D2);
}
void stop()
{
   output_low(PIN_B6);
   output_low(PIN_B7);
   output_low(PIN_D1);
   output_low(PIN_D3);
   output_low(PIN_D0);
   output_low(PIN_D2);
}
//-----------------Subrutinas del control del brazo------------------------
void altura_arriba()
{
   set_pwm1_duty(80);
   set_pwm2_duty(0);
   output_high(PIN_D4);
   output_low(PIN_D5);
   
}

void altura_abajo()
{
   set_pwm1_duty(80);
   set_pwm2_duty(0);
   output_low(PIN_D4);
   output_high(PIN_D5);  
}

void apertura()
{
   set_pwm1_duty(0);
   set_pwm2_duty(80);
   output_low(PIN_D6);
   output_high(PIN_D7);
}

void cierre()
{
   set_pwm1_duty(0);
   set_pwm2_duty(80);
   output_low(PIN_D6);
   output_high(PIN_D7);
}

void stop_alt()
{
   set_pwm1_duty(0);
   set_pwm2_duty(0);
   output_low(PIN_D4);
   output_low(PIN_D5);
}

void stop_cierre()
{
   set_pwm1_duty(0);
   set_pwm2_duty(0);
   output_low(PIN_D4);
   output_low(PIN_D5);
}

//--------------------------Configuracion del PIC-----------------------------
void cpu()
{

   setup_psp(PSP_DISABLED);
   setup_spi(SPI_SS_DISABLED);
   setup_wdt(WDT_OFF);
   setup_timer_0(RTCC_INTERNAL);
   setup_timer_1(T1_DISABLED);
   setup_timer_2(T2_DIV_BY_4,88,1);
   setup_timer_3(T3_DISABLED|T3_DIV_BY_1);
   setup_ccp1(CCP_PWM);
   setup_ccp2(CCP_PWM);
   set_pwm1_duty(0);
   set_pwm2_duty(0);
   setup_comparator(NC_NC_NC_NC);
   enable_interrupts(INT_RDA);
   enable_interrupts(INT_EXT2);
   enable_interrupts(GLOBAL);

   
   //0x00 Salida
   //0xFF Entrada
   set_tris_A(0xFF); 
   SET_TRIS_B(0b00111111); 
   SET_TRIS_C(0b10111110);
   SET_TRIS_D(0X00);
   SET_TRIS_E(0xFF);
 
}

//Programa Princicpal
void main()
{
   cpu();
   //Led para saber que el progrma inicio
   output_high(PIN_C0);
   delay_ms(100);
   output_low(PIN_C0);
   delay_ms(100);
   
   while(true)
   {

    if(CAR=='a'){
      adelante();
      output_high(PIN_C0);
      delay_ms(100);
      output_low(PIN_C0);
      delay_ms(100);
    }
    if(CAR=='b'){
      atras();
      output_high(PIN_C0);
      delay_ms(100);
      output_low(PIN_C0);
      delay_ms(100);
    }
    if(CAR=='c'){
      stop();
      output_high(PIN_C0);
      delay_ms(100);
      output_low(PIN_C0);
      delay_ms(100);
    }
    if(CAR=='d'){
      derecha_adelante();
      output_high(PIN_C0);
      delay_ms(100);
      output_low(PIN_C0);
      delay_ms(100);
    }
    if(CAR=='e'){
      izquierda_adelante();
      output_high(PIN_C0);
      delay_ms(100);
      output_low(PIN_C0);
      delay_ms(100);
    }
   }
}

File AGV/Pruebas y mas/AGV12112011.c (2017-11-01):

//***************************************************************************************************
//---------------------Programa de un AGV Electronica y Mecanica----------------
//-------------------------31 de Octubre del 2011------------------------------
//---------------Programacion: Andres Eduardo Sabas Jimenez--------------------
//-----------------Diseño:                                           ------------
//-----------------------Objetivo: Lograr un vehiculo no tripulado-------------- 
//-----------------con opcion hibrida automatica y manual, con comunicacion bluethoot-----------
//----------------------asi como poder soportar una pantalla touch--------------
//****************************************************************************************************
//#include <AGV.h>
#include <18F4550.h>
#device adc=8

#FUSES NOWDT                    //No Watch Dog Timer
#FUSES WDT128                   //Watch Dog Timer uses 1:128 Postscale
#FUSES HS                       //High speed Osc (> 4mhz for PCM/PCH) (>10mhz for PCD)
#FUSES NOPROTECT                //Code not protected from reading
#FUSES NOBROWNOUT               //No brownout reset
#FUSES BORV20                   //Brownout reset at 2.0V
#FUSES PUT                      //Power Up Timer
#FUSES NOCPD                    //No EE protection
#FUSES STVREN                   //Stack full/underflow will cause reset
#FUSES NODEBUG                  //No Debug mode for ICD
#FUSES NOLVP                    //No low voltage prgming, B3(PIC16) or B5(PIC18) used for I/O
#FUSES NOWRT                    //Program memory not write protected
#FUSES NOWRTD                   //Data EEPROM not write protected
#FUSES IESO                     //Internal External Switch Over mode enabled
#FUSES FCMEN                    //Fail-safe clock monitor enabled
#FUSES PBADEN                   //PORTB pins are configured as analog input channels on RESET
#FUSES NOWRTC                   //configuration not registers write protected
#FUSES NOWRTB                   //Boot block not write protected
#FUSES NOEBTR                   //Memory not protected from table reads
#FUSES NOEBTRB                  //Boot block not protected from table reads
#FUSES NOCPB                    //No Boot Block code protection
#FUSES MCLR                     //Master Clear pin enabled
#FUSES LPT1OSC                  //Timer1 configured for low-power operation
#FUSES NOXINST                  //Extended set extension and Indexed Addressing mode disabled (Legacy mode)
#FUSES PLL12                    //Divide By 12(48MHz oscillator input)
#FUSES CPUDIV4                  //System Clock by 4
#FUSES USBDIV                   //USB clock source comes from PLL divide by 2
#FUSES VREGEN                   //USB voltage regulator enabled
#FUSES ICPRT                    //ICPRT enabled

#use delay(crystal=20000000,  clock=3000000)


//---------- Configuro el uso del puerto serial-------
#use rs232(baud=19200, xmit=PIN_C6,rcv=PIN_C7,RESTART_WDT)

//--------------Configuro el uso de I2C------------------

#use i2c(Master,sda=PIN_D0,scl=PIN_D1,Slow,force_hw)

//-----------------Se le pide a picc que no mueva los TRIS de los puertos
#use FAST_IO(A)
#use FAST_IO(B)
#use FAST_IO(C)
#use FAST_IO(D)
#use FAST_IO(E)

//----------------Seccionde definicion de bits utlizados------------------------
#bit LED=0xF82.0   //Direccion logica del led   

//------------------------ Variables globales-----------------------------------
   long VAL_ADC;
   unsigned char cmd, blue;
   int a, com;
   
//******************************************************************************
//------------------------- Interrupciones--------------------------------------
//******************************************************************************
//------------------------Subrutina de encoder---------------------------------
/*#int_EXT
void  EXT_isr(void) 
{
   a++;
}
//---------------------Interrupciondel rs232-----------------------------------
#int_RDA
void  RDA_isr(void) 
{
 if(com=0)
   {
   cmd=getc(); //Espera de instruccion manual o automatico
   }
  else
  {
   blue=getc(); //Comunicacion con el bluetooht
  }
 
}*/
//******************************************************************************

//-----------------Subrutina que enciende y me apaga un led---------------------
void FLASHEO(unsigned char TIE)
{
   LED=1;
   delay_ms(TIE);
   LED=0;
   delay_ms(TIE);
   LED=1;
   delay_ms(TIE);
   LED=0;
   delay_ms(TIE);
 
   return;

}
//******************SUBRUTINAS DEL GIRO DEL MOTOR********************************
//----------Subrutina de Giro a la derecha---------
void DERECHA(void)
{
      set_pwm1_duty(76);
      set_pwm2_duty(38);
}

//----------Subrutina de Giro a la Izquierda---------
void IZQUIERDA(void)
{
      set_pwm1_duty(76);
      set_pwm2_duty(38);
}
//***********************SUBRUTINAS DEL BRAZO**********************************
//----------Subrutina de cierre de pinza---------
void CIERRE(void)
{

}
//----------Subrutina de levantamiento de la pinza---------
void ALTURA(void)
{

}

//********************SUBRUTINAS MAESTRAS**************************************
//*****************************************************************************
//------------------Subrutina de modo manual
void manual()
{
   com=1; //Se a seleccionado el modo y ahora se enviaran comandos del bluethoot
   
}
//-----------------Subrutina de modo automatico
void automatico()
{
   /*com=1; //Se a seleccionado el modo y ahora se enviaran comandos del bluethoot
   while(1)
      {
        if(input(pin_A0)==1 && input(pin_A1)==1)
        {
         ADELANTE();
        }
        if(input(pin_A0)==1 && input(pin_A1)==0)
        {
         DERECHA();
        }
        if(input(pin_A0)==0 && input(pin_A1)==1)
        {
         IZQUIERDA();
        }
        if(input(pin_A0)==0 && input(pin_A1)==0)
        {
        SALIDA();
        }

      }*/
}
//---  Subrutina de configuracion----------
void INI_CPU(void)
{

   setup_adc_ports(NO_ANALOGS|VSS_VDD);
   setup_adc(ADC_CLOCK_DIV_2);
   setup_psp(PSP_DISABLED);
   setup_spi(SPI_SS_DISABLED);
   setup_wdt(WDT_OFF);
   setup_timer_0(RTCC_INTERNAL);
   setup_timer_1(T1_DISABLED);
   setup_timer_2(T2_DIV_BY_16,77,1);
   //setup_ccp1(CCP_PWM_FULL_BRIDGE|CCP_SHUTDOWN_AC_L|CCP_SHUTDOWN_BD_L);
   setup_ccp1(CCP_PWM);
   setup_ccp2(CCP_PWM);
   set_pwm1_duty(0);// Motor derecho
   set_pwm2_duty(0);// Motor Izquierdo
   setup_comparator(NC_NC_NC_NC);
   
   //0x00 Salida
   //0xFF Entrada
   set_tris_A(0xFF); 
   SET_TRIS_B(0XFF); 
   SET_TRIS_C(0X00);//CCP1 y 2 Salida
   //SET_TRIS_D(0XFF);
   SET_TRIS_E(0xFF); 
   output_float(PIN_D0);         //I2C pin float 
   output_float(PIN_D1);         //I2C pin float 
   
   return;

}
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
